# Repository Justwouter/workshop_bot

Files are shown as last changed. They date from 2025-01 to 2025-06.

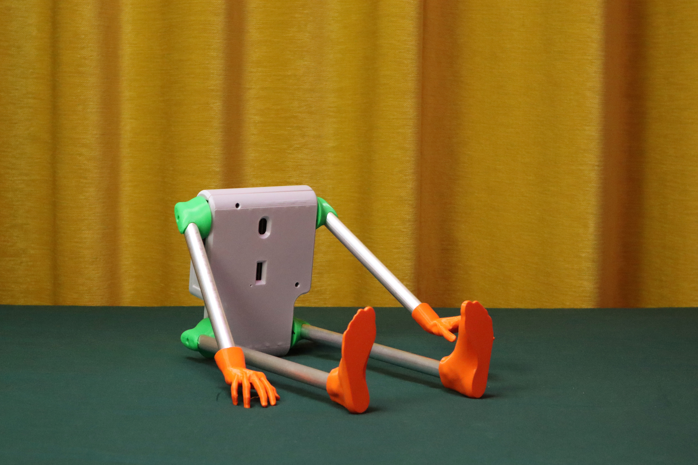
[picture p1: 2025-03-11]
media/IMG_3838.JPG

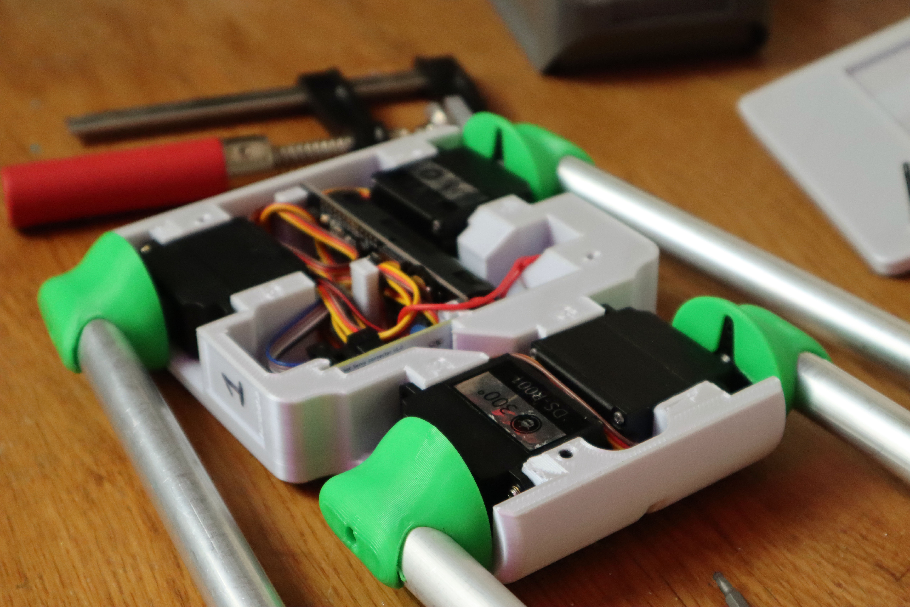
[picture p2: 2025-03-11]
media/IMG_4038.JPG

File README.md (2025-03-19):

Welcome to the Acrobot Workshop bot

This is a small version of the [Acrobot](https://Acrobot.nl), a simple but expressive robot acrobat with 4 joints. It is easy to animate by using [Bottango](https://www.bottango.com/).

The project was developed by [Daniel Simu](https://danielsimu.com), with funding and support from [Creative Coding Utrecht](https://creativecodingutrecht.nl/).
Additional materials were sponsored by [DFRobot](https://www.dfrobot.com/),  [Fillamentum](https://fillamentum.com/) and [Tinytronics](https://www.tinytronics.nl/en/)

https://github.com/user-attachments/assets/d1673c57-b2f6-4ec9-994d-3f826fc23f9e

# Required materials

For a workshop you need 3 things:
- Workshop bot
- ESP-NOW dongle
- Computer with Bottango software
  
Typically 2 - 3 participants can use 1 robot kit.



## Bottango

- The Bottango project file can be found in this repo.
- The ESP-NOW dongle is flashed with the BottangoArduinoDriver in parent mode, and connected to the computer running Bottango
- The ESP32 on the robot is running the BottangoArduinoDriver in child  mode

Make sure to update the child code with the mac address of the parent, and in Bottango enter the mac address of the child and the COM port in the hardware settings.

## Building the robot

3d model files, schematics and pcb gerber files are in the repo.

- The body consists of 2 3d printed halves, in PLA
- The shoulders, hips, hands and feet are best printed of TPU98A from [Fillamentum](https://fillamentum.com/)
- The motors are ideally 6Kg 300° Clutch Servos from [DFRobot](https://www.dfrobot.com/) 
- The ideal ESP32 for the robot is this [TTGO-T18](https://github.com/LilyGO/TTGO-T-Cell), which comes with a battery holder and a button. You can get these from [Tinytronics](https://www.tinytronics.nl/en/development-boards/microcontroller-boards/with-wi-fi/lilygo-ttgo-t-cell-esp32-with-3-way-button-and-18650-battery-holder)
  - I recommend squeezing a protected 18650 cell into the battery holder, the holder terminals may need to be bent to fit this.
- The dongle can be any standard ESP32, I use a Pico-d4 with a usb plug connector mounted on it.
- You can solder the electronics together on a perfboard, or fabricate the pcb.
- You will need 2 small screws to hold the ESP(2x6mm works well), and 3 M3 nuts and M3x30mm bolts to close the case.
- 16mm alluminium tubes are used for arms and legs, recommended sizes are 190mm and 290mm



# Todo

- Write detailed instructions about how to fabricate and assemble the motors
- Write workshop instructions
- Improve robot design

# License

This project is shared under the Creative Commons Attribution 4.0 International license. 

We're open to consider other licenses that are better suited for open hardware design.

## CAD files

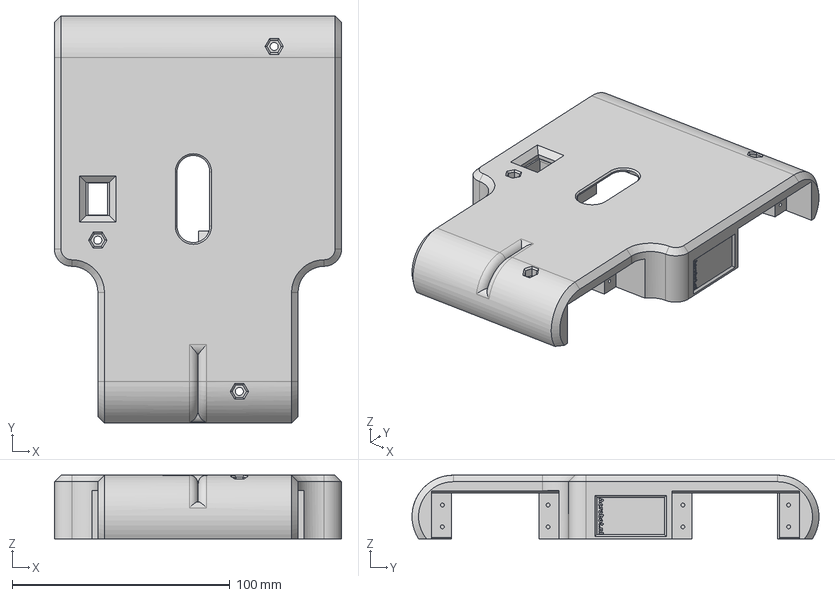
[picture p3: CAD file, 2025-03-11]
3d_print/wsbot torso v28.step
132.0 x 187.0 x 29.2 mm

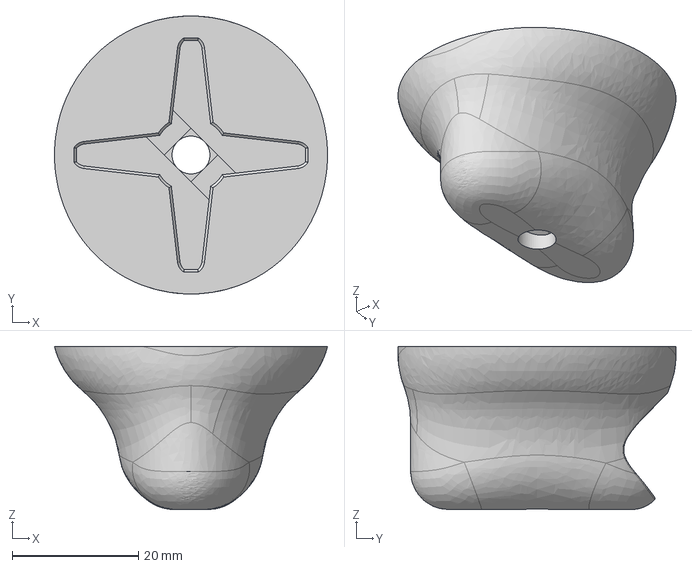
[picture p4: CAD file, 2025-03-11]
3d_print/horn_fitting leg 4star v7.step
43.2 x 44.0 x 25.8 mm

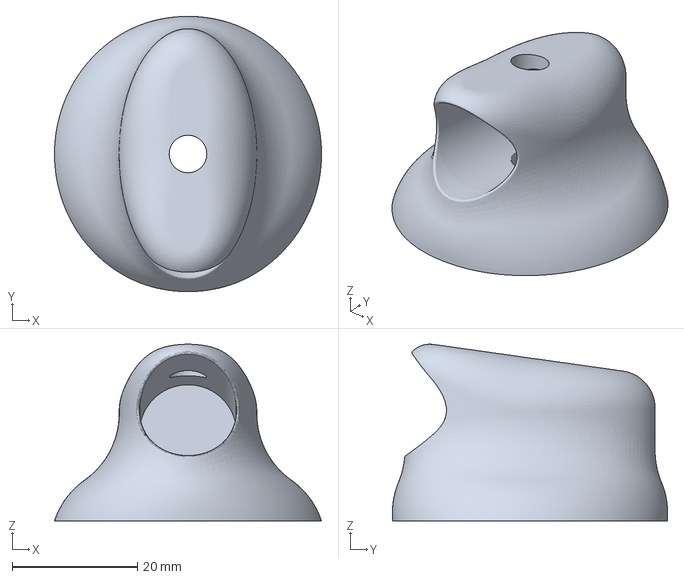
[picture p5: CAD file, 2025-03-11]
3d_print/horn_fitting arm 4star v5.3mf
42.7 x 44.0 x 28.2 mm

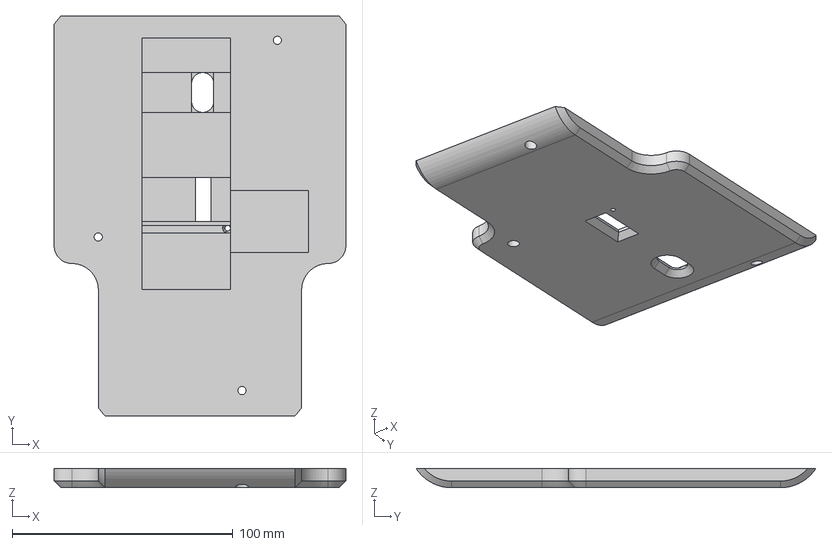
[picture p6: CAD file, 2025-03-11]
3d_print/wsbot lid v24.step
132.0 x 181.0 x 8.75 mm

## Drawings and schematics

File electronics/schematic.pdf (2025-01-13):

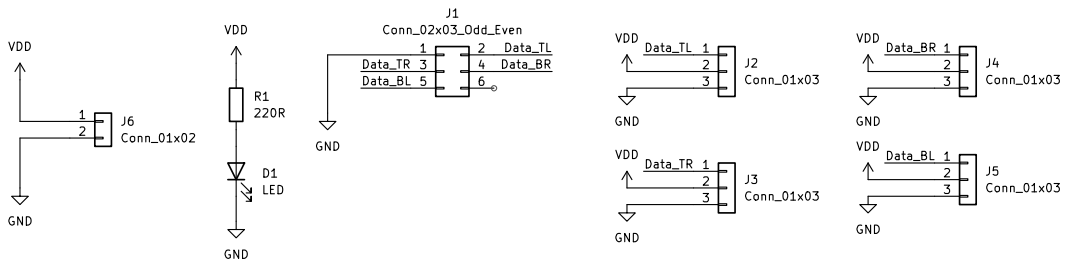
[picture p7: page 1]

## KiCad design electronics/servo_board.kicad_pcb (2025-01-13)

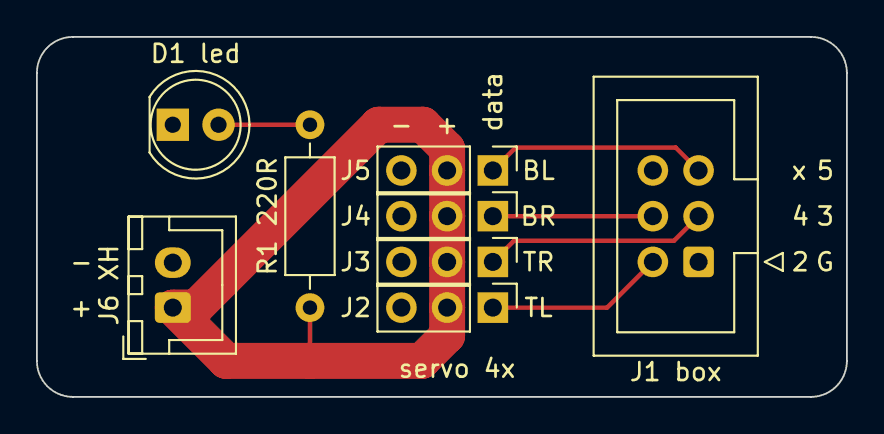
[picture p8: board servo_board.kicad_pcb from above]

Board: 2 copper layers, 45.0 x 20.0 mm, 8 parts (0 on the bottom side), 7 nets.

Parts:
D1 led: LED; LED_D5.0mm
J1 box: Conn_02x03_Odd_Even; IDC-Header_2x03_P2.54mm_Vertical
J2, J3, J4, J5: Conn_01x03; PinHeader_1x03_P2.54mm_Vertical
J6 XH: Conn_01x02; JST_XH_B2B-XH-A_1x02_P2.50mm_Vertical
R1 220R: 220R; R_Axial_DIN0207_L6.3mm_D2.5mm_P10.16mm_Horizontal

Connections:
/Data_BL: J1 box.5, J5.1
/Data_BR: J1 box.4, J4.1
/Data_TL: J1 box.2, J2.1
/Data_TR: J1 box.3, J3.1
GND: D1 led.1 (K), J1 box.1, J2.3, J3.3, J4.3, J5.3, J6 XH.2
unnamed: D1 led.2 (A), R1 220R.2
VDD: J2.2, J3.2, J4.2, J5.2, J6 XH.1, R1 220R.1

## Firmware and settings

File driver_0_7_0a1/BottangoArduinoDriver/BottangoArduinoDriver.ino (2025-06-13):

// !!! DRIVER VERSION: 0.7.0a1 !!!
// !!! Api Version: 8 !!!

// Modified by Daniel Simu for the Acrobot Workshop
// https://github.com/hapiel/workshop_bot

#include "src/BottangoCore.h"
#include "src/BasicCommands.h"

#include <WiFi.h>
#include <HTTPClient.h>
#include <esp_wifi.h>

// == Wouter's Stuff ==
// Definitions
const int middleButtonPin = 36;  // should align with onboard buttons
// Replace with your WiFi credentials
const char *ssid = "CKC DigitalArtLab";
const char *password = "digitalartlab";

// Replace with your target URL
const char *serverUrl = "http://10.0.1.74:59224/ControlInput/";

bool buttonState = false;
bool wifiMode = false;

struct MotorData {
  String bottangoIdentifier;
  int feedbackPin;
  bool inverted = false;
};

MotorData motors[2] = {
  { "legLeft", 32, true },
  { "legRight", 33, false }
};

// Wifi Stuff
void readMacAddress() {
  uint8_t baseMac[6];
  esp_err_t ret = esp_wifi_get_mac(WIFI_IF_STA, baseMac);
  if (ret == ESP_OK) {
    Serial.printf("%02x:%02x:%02x:%02x:%02x:%02x\n",
                  baseMac[0], baseMac[1], baseMac[2],
                  baseMac[3], baseMac[4], baseMac[5]);
  } else {
    Serial.println("Failed to read MAC address");
  }
}

void disconnectWiFi() {
  if (WiFi.status() == WL_CONNECTED) {
    WiFi.disconnect();
    Serial.println("Disconnected from WiFi");
  } else {
    Serial.println("WiFi is not connected");
  }
}

void setupWiFi() {
  Serial.print("Connecting to WiFi");
  WiFi.begin(ssid, password);
  readMacAddress();
  while (WiFi.status() != WL_CONNECTED) {
    delay(500);
    Serial.print(".");
  }
  Serial.println("\nConnected to WiFi");

  sendDataToBottango(motors[0]);  // Send intial data as test
}

bool sendDataToBottango(MotorData data) {
  if (WiFi.status() == WL_CONNECTED) {
    HTTPClient http;

    http.begin(serverUrl);
    http.addHeader("Content-Type", "application/json");

    String valueString = String(normalizeServoValue(data));  // Normalize the servo value to 4 decimal places
    String jsonData = "{\"identifier\":\"" + String(data.bottangoIdentifier) + "\", \"value\":" + valueString + "}";
    Serial.println("HTTP PUT request with data: " + jsonData);
    int httpResponseCode = http.PUT(jsonData);  // PUT request

    if (httpResponseCode > 0) {
      Serial.print("HTTP Response code: ");
      Serial.println(httpResponseCode);
      String response = http.getString();
      Serial.println("Response:");
      Serial.println(response);
      return true;
    } else {
      Serial.print("Error in PUT request: ");
      Serial.println(http.errorToString(httpResponseCode));
      return true;
    }

    http.end();  // Free resources
    return true;
  } else {
    Serial.println("WiFi not connected");
    return false;
  }
  // delay(500);
}

void sendAllToBottango() {
  for (int i = 0; i < sizeof(motors) / sizeof(motors[0]); i++) {
    if (!sendDataToBottango(motors[i])) {
      Serial.println("Failed to send data for " + String(motors[i].bottangoIdentifier));
    }
  }
}

void wifiLoop() {
  buttonState = digitalRead(middleButtonPin);
  if (buttonState == LOW && wifiMode == false) {
    BottangoCore::effectorPool.clearAllCurves();
    BottangoCore::effectorPool.deregisterAll();

    BottangoCore::stop();

    setupWiFi();
    Serial.println("engage wifi");
    wifiMode = true;
    Serial.println(wifiMode);
    delay(500);
  } else if (buttonState == LOW && wifiMode == true) {
    esp_system_abort("Hello");
    Serial.println("stop wifi");
    wifiMode = false;
    Serial.println(wifiMode);
    delay(500);
  }

  if (wifiMode == true) {
    sendAllToBottango();
  }
  if (wifiMode == false) {
    BottangoCore::bottangoLoop();
  }
}

// Servo Stuff

float normalizeServoValue(MotorData data) {
  float value = analogRead(data.feedbackPin);
  // normalize to 0-1 range by deviding trough the max petentiometer value
  value = value > 0 ? value / 4095 : 0;
  if (data.inverted) {
    value = 1 - value;
  }
  return value;
}

void clearScrean() {
  for (int i = 0; i < 100; i++) {
    Serial.print("\n");
  }
}

void printRawServo() {
  // clearScrean();
  for (int i = 0; i < sizeof(motors) / sizeof(motors[0]); i++) {
    Serial.print(String(analogRead(motors[i].feedbackPin)) + " ");
  }
  Serial.println("");
}

// == Daniel's Stuff ==
const int ledPin = 21;
int ledState = LOW;  // Variable to store the state of the LED
unsigned long previousMillis = 0;

void blinkWithoutDelay(unsigned long onTime, unsigned long offTime) {
  // Get the current time
  unsigned long currentMillis = millis();

  // Check if it's time to change the state of the LED
  if ((ledState == HIGH) && (currentMillis - previousMillis >= onTime)) {
    ledState = LOW;                  // Turn LED off
    previousMillis = currentMillis;  // Save the time
    digitalWrite(ledPin, ledState);  // Update the LED
  } else if ((ledState == LOW) && (currentMillis - previousMillis >= offTime)) {
    ledState = HIGH;                 // Turn LED on
    previousMillis = currentMillis;  // Save the time
    digitalWrite(ledPin, ledState);  // Update the LED
  }
}

uint32_t printTimer = 0;

void printInfo() {
  int battRaw = analogRead(35);
  float battVolt = battRaw * (3.3 / 4096) * 2;
  int battPercent = map(battVolt * 100, 250, 420, 0, 100);

  // print status every 3 seconds
  if (printTimer + 3000 < millis()) {
    printTimer = millis();
    Serial.printf("bat: %f v %d - %d \n", battVolt, battPercent, battRaw);
    readMacAddress();
  }

  // check battery status with button
  if (!digitalRead(36)) {
    if (battPercent > 75) {
      digitalWrite(ledPin, HIGH);
    } else if (battPercent > 50) {
      blinkWithoutDelay(300, 50);
    } else if (battPercent > 25) {
      blinkWithoutDelay(200, 200);
    } else {
      blinkWithoutDelay(100, 400);
    }
  } else {
    digitalWrite(ledPin, LOW);
  }
}

void setup() {
  Serial.begin(115200);
  // setupWiFi();

  pinMode(34, INPUT);
  pinMode(36, INPUT);  // middle button
  pinMode(39, INPUT);
  pinMode(ledPin, OUTPUT);
  BottangoCore::bottangoSetup();
}

void loop() {
  wifiLoop();
  printInfo();
  // printRawServo();
  // BottangoCore::bottangoLoop();
}

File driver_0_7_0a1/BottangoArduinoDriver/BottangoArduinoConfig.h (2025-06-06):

#ifndef DevConsts_h
#define DevConsts_h

#include "BottangoArduinoModules.h"
#include <Arduino.h>

// !! Max Registered Motors !!
// Max effectors (motors, etc.) that can be registered at once.
// more than 8 crashes an Arduino Uno / Nano
// otherwise capped by default at 16, but can be increased if needed (depending on your hardware)

#if defined(ARDUINO_AVR_UNO) || defined(ARDUINO_AVR_NANO)
#ifdef USE_ADAFRUIT_PWM_LIBRARY
#define MAX_REGISTERED_EFFECTORS 6 // Arduino Uno or Nano + PCA driver can only support 6
#else
#define MAX_REGISTERED_EFFECTORS 8 // Arduino Uno or Nano bare pin pwm supports 8
#endif
#else
#define MAX_REGISTERED_EFFECTORS 16 // most modern boards can handle 16 or more (EX, ESP32, etc.)
#endif

// ---------------------------------- //

// !! Module Configuration !!

// !! Wifi Configuration !!
#ifdef USE_ESP32_WIFI
#define WIFI_SSID "MY_NETWORK_ID"                   // wifi ssid
#define WIFI_PASSWORD "MY_NETWORK_PW"               // wifi password
#define WIFI_SERVER_IP "XXX.XXX.XXX.X"              // wifi server ip on the local network, likely something like 192.168.1.X
#define WIFI_SERVER_PORT 59225                      // wifi server port on the local network
#endif

// !! Module Pins Configuration !!

// !! SD Card Pin Configuration !!
// Note that Arduino Uno / Nano are not supported with SD Card
#if defined(USE_SD_CARD_COMMAND_STREAM) || defined(AUDIO_SD_I2S)
#define SDPIN_CS 5                                  // chip select pin
#ifdef ESP32                                        // spi pins
#define SDPIN_MOSI 23                               // MOSI pin
#define SDPIN_CLK 18                                // clock pin
#define SDPIN_MISO 19                               // MISO pin
#endif
#endif

// !! Dynamic switch between live and exported animations !!
#ifdef ENABLE_DYNAMIC_ANIMATION_SOURCE_SWITCH
#define ANIMATION_STATE_SELECTION_PIN 36            // Pin to monitor on boot to determine if should be in live control or exported
#define SELECT_EXPORTED_IS_LOW                     // LOW on pin selects exported. Comment out this line to choose exported on highs.
#endif

// !! I2S and Audio Pins !!
#ifdef AUDIO_SD_I2S
#define I2S_BCLK 25                                 // bit clock line
#define I2S_LRC 17                                  // left right clock
#define I2S_DOUT 16                                 // data
#ifdef DYNAMIC_VOLUME
#define VOLUME_PIN 35
#define VOLUME_MIN 1.0;
#define VOLUME_MAX 0.01;
#endif
#ifdef PIN_ON_AUDIO_PLAY
#define AUDIO_ENABLE_PIN 2
#endif
#endif


// !! SD Card Pin Configuration !!
// Note that Arduino Uno / Nano are not supported with SD Card

// ---------------------------------- //

// !! The below are ADVANCED configurations !!

// Curve Evaluation:
// enable one of the bezier curve default evaluation methods:
#define DEFAULT_FLOAT_CURVE // float math option (default, battle hardened and highly tested)
// #define DEFAULT_FIXED_CURVE                      // fixed math option. Slightly lower curve precision, but faster.  Likely will see improved HW communication and higher max effector count. New and being tested.


#define AVR_STEPPER_FIXED                           // in order to keep up with the demands of stepper motors, AVR boards (Arduino Uno, Nano, Mega, etc) use
                                                    // fixed evaluation overriding the above default. Comment this line out to use the default curve evaluation on avr steppers

#define VELOCITY_SEGMENT_MS 67                      // Velocity effectors (IE steppers) will segment curves into chunks of velocity. This field defines how long each chunk is in MS.
                                                    // lower number means more segments. More segments will be more accurate to the curve, but slower to process and less smooth stepper movement
                                                    // If you wanted to target 15 segments per second (the default) divide 1000 by 15: 1000 / 15 = 66.666, so rounded to 67
                                                    // 30 segments per second would be 33, etc.

#define STEPPER_SYNC_SPEED 2                        // steppers will sync at 1/X percent of max speed. IE, 2 == 50% max speed, 4 == 25% max Speed, etc.
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

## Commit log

2025-02-25 new driver
2025-03-11 files v2
    [horn_fitting arm 4star v5.3mf, horn_fitting arm v4.step, horn_fitting leg 4star v7.step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]
2025-06-06 Restructure ino, add servo read
2025-06-13 Invert left motor, add wifi disconnect , fix normalizing servo
    [BottangoArduinoDriver.ino, BottangoArduinoModules.h]
2025-06-13 Fuckery with servos
